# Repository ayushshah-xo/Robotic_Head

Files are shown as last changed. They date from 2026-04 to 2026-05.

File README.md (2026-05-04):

<div align="center">

Stack ticker

<br/>

# 🤖 Humanoid Robot

**An open-source AI-powered robot with real-time voice conversation, expressive servo-driven facial animations, and a fully 3D-printed chassis — built on Raspberry Pi 4.**

<br/>






</div>

---

## What is this?

A fully functional humanoid robot built from scratch — mechanical design, embedded hardware, and AI software — by a student. It listens to you, thinks, responds aloud, and moves its face to match.

No cloud subscriptions. No black-box kits. Every part designed, printed, and coded by hand.

<br/>

<div align="center">

| Robot front view | CAD design | System diagram |
|:---:|:---:|:---:|
| **Built Robot** | **CAD Design** | **System Flow** |

</div>

---

## Demo

https://github.com/user-attachments/assets/923eefe1-8b44-4f8e-96d7-886b42254e04

> Servo-driven facial expressions running in real time — eyes, eyebrows, and mouth animated independently.
>

---
## Features

| | |
|---|---|
| 🎤 **Voice I/O** | Listens via mic, responds via speaker |
| 🧠 **AI Brain** | Online + offline conversation modes |
| 😐 **Facial Expressions** | Servo-driven eyes, eyebrows, and mouth |
| ⚡ **Real-time** | Low-latency speech-to-response pipeline |
| 🧩 **Modular** | Swap hardware or swap AI model independently |
| 🖨️ **3D Printed** | Every structural part is printable and remixable |

---

## How it works

```
You speak
   ↓
Speech Recognition  ──── converts audio to text
   ↓
AI Model  ──────────────  generates a response
   ↓
Text-to-Speech  ─────────  synthesizes audio
   ↓
Speaker output  +  Servo animation  (synced mouth movement)
```

The servo controller runs in a separate thread so facial animation stays in sync with audio playback without blocking the main pipeline.

---

## Hardware

| Component | Purpose |
|---|---|
| Raspberry Pi 4 | Main compute |
| Servo motors (×3) | Face actuation |
| Servo driver board | PCA9685 |
| USB microphone | Speech input |
| Speaker + amplifier | Audio output |
| 5V regulated supply | Motor power |
| 3D printed chassis | Structure |

> Wiring guide and GPIO pin map are in [`docs/hardware-setup.md`](docs/hardware-setup.md)

---

## Getting started

**Requirements:** Python 3.9+, Raspberry Pi OS (64-bit recommended)

```bash
# 1. Clone
git clone https://github.com/ayushshah-xo/Humanoid-Robot-.git
cd Humanoid-Robot-

# 2. Install dependencies
pip install -r requirements.txt

# 3. Configure (copy and edit)
cp config.example.yaml config.yaml

# 4. Run
python3 main.py
```

> **First time?** See [`docs/quickstart.md`](docs/quickstart.md) for a step-by-step walkthrough including hardware connection and audio device setup.

---
## Libraries

Two kinds of dependencies power this project — Python packages and system-level tools.

**Python packages** — installed via pip:

| Package | Purpose |
|---|---|
| `adafruit-circuitpython-servokit` | PCA9685 servo driver control |
| `groq` | Online AI via Groq (Llama 3) |
| `SpeechRecognition` | Converts microphone audio to text |
| `pyaudio` | Raw audio stream for the mic |
| `requests` | HTTP calls to Groq and Ollama |
| `pyyaml` | Reads `config.yaml` at startup |

```bash
pip install -r requirements.txt
```

**System packages** — installed via apt:

| Package | Purpose |
|---|---|
| `espeak` | Offline text-to-speech engine |
| `python3-pyaudio` | PyAudio system binding |
| `portaudio19-dev` | Audio I/O backend |
| `alsa-utils` | Audio device control (`aplay`, `alsamixer`) |

```bash
sudo apt install espeak python3-pyaudio portaudio19-dev alsa-utils
```

**Offline AI engine** — Ollama runs locally on the Pi as a fallback when there is no internet:

```bash
curl -fsSL https://ollama.com/install.sh | sh
ollama pull tinyllama
```

> The robot automatically switches between Groq (online) and Ollama (offline) — no manual intervention needed.

---
## Folder structure
<p align="center">
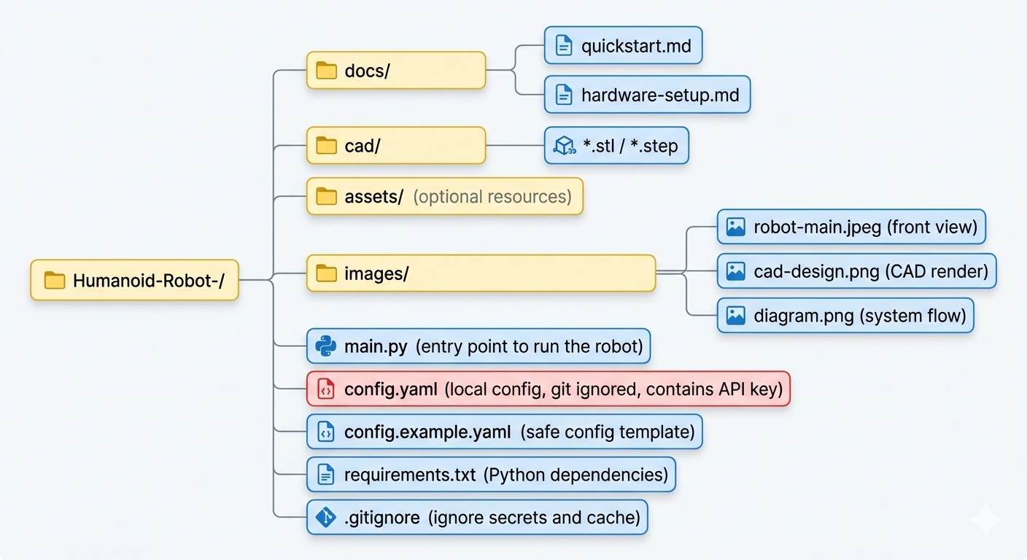
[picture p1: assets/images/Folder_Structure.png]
  
</p>

> ⚠️ config.yaml holds your API key — it is blocked by .gitignore and will never be pushed to GitHub. Only edit config.example.yaml when changing config structure.
---

## CAD & 3D printing

All structural files are in [`/cad`](cad/). Designed to be:

- Printed on any FDM printer (PLA recommended)
- Assembled with standard M3 hardware
- Modular — replace individual parts without reprinting everything

---

## Roadmap

- [ ] Face recognition — recognize known people
- [ ] Emotion AI — adapt expression to conversation tone
- [ ] Mobile app — wireless control and monitoring
- [ ] Locomotion — basic autonomous movement

---

## Contributing

Issues, pull requests, and forks are welcome.

If you improve a module or add a new one, open a PR — this project is meant to be remixed.

---

If this project helped you or inspired you — a ⭐ goes a long way.

</div>

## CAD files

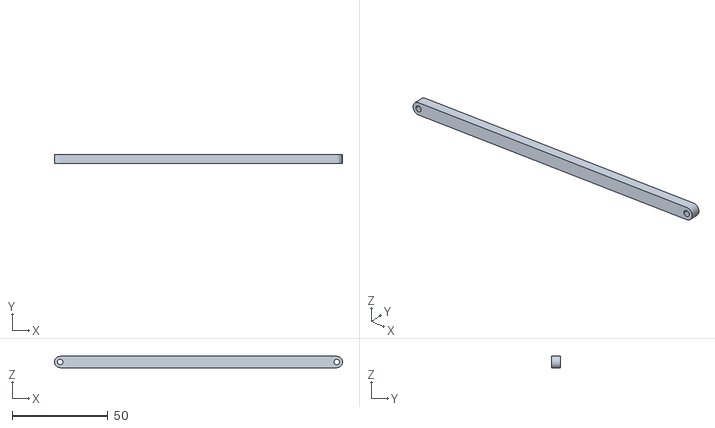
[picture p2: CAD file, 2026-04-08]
cad/Neck/neck_stroke.stl
150.2 x 4.70 x 6.00

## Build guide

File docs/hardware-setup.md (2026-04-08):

# 🤖 Hardware Setup — Humanoid Robot

> **This document explains every wire and connection in the robot.**
> Even if you've never built a robot before, you'll understand this by the end!

---

## 📋 Table of Contents

- [What's Inside the Robot?](#whats-inside-the-robot)
- [Parts List](#parts-list)
- [How Everything Connects](#how-everything-connects)
  - [Raspberry Pi → PCA9685 Servo Driver](#1-raspberry-pi--pca9685-servo-driver)
  - [Servo Motors (Eyes & Jaw)](#2-servo-motors-eyes--jaw)
  - [Power Supply](#3-power-supply)
  - [USB Microphone](#4-usb-microphone)
  - [Speaker (Audio Jack)](#5-speaker-audio-jack)
- [Wiring Diagram](#wiring-diagram)
- [Pinout Reference](#pinout-reference)
- [Quick-Reference Table](#quick-reference-table)
- [Credits](#credits)

---

## 🧠 What's Inside the Robot?

Think of the robot's brain like a tiny computer — that's the **Raspberry Pi 4**. It tells the eyes and jaw when to move, listens through a microphone, and talks through a speaker. The **PCA9685** is a helper chip that controls all the motors so the Raspberry Pi doesn't get overloaded.

```
[ Microphone ] ──USB──┐
[ Speaker ]  ──3.5mm──┤
                       ├──► Raspberry Pi 4 ──I2C──► PCA9685 ──PWM──► Servo Motors
[ 5V Power ] ─────────┘                                │
                                              [ 5V Power for Servos ]
```

---

## 🛒 Parts List

| # | Part | Quantity | What it does |
|---|---|---|---|
| 1 | Raspberry Pi 4 | 1 | The brain — runs all the code |
| 2 | PCA9685 16-Channel PWM Driver | 1 | Controls all servo motors |
| 3 | Servo Motor (for eye blinking) | 3 | Opens and closes the eyelids |
| 4 | Servo Motor (for jaw movement) | 1 | Opens and closes the mouth |
| 5 | USB Microphone | 1 | Listens to what you say |
| 6 | Speaker (3.5mm audio jack) | 1 | Lets the robot talk back |
| 7 | 5V Power Supply | 2 | Powers the Pi and the servos separately |
| 8 | Jumper Wires (Female-to-Female) | Several | Connect everything together |

---

## 🔌 How Everything Connects

### 1. Raspberry Pi → PCA9685 Servo Driver

The Raspberry Pi talks to the PCA9685 using a communication method called **I2C** — it only needs 4 wires!

> 💡 **Simple explanation:** I2C is like a telephone line. The Pi is the boss, and the PCA9685 picks up the call and moves the motors.

| Wire Color | Raspberry Pi Pin | PCA9685 Pin | Purpose |
|---|---|---|---|
| 🔴 Red | Pin 1 (3.3V) | VCC | Power for the chip's brain |
| ⚫ Black | Pin 6 (Ground) | GND | Completes the circuit (return path) |
| 🟡 Yellow | Pin 3 (BCM 2 / SDA) | SDA | Sends data |
| 🟢 Green | Pin 5 (BCM 3 / SCL) | SCL | Keeps data in sync (clock) |

---

### 2. Servo Motors (Eyes & Jaw)

Servo motors plug directly into the **PCA9685 board** using the PWM headers along the bottom edge. Each servo has 3 wires:

- 🔴 **Red** → V+ (Positive power)
- ⚫ **Brown/Black** → GND (Ground)
- 🟡 **Yellow/Orange** → PWM signal (tells the motor what angle to move to)

| Servo | PCA9685 Channel | Function |
|---|---|---|
| Eye Servo 1 | Channel 0 | Left eye blink |
| Eye Servo 2 | Channel 1 | Right eye blink |
| Eye Servo 3 | Channel 2 | Upper eyelid control |
| Jaw Servo | Channel 3 | Jaw open / close |

> 💡 **Simple explanation:** Imagine the PCA9685 is a TV remote. Each channel is a button, and each servo is a TV. Press button 0 → Eye 1 moves!

---

### 3. Power Supply

The robot needs **two separate power supplies**:

#### ⚡ Power for the Raspberry Pi
- Use an official **5V USB-C power adapter** (at least 3A recommended)
- Plug it directly into the **USB-C port** on the Raspberry Pi 4

#### ⚡ Power for the Servo Motors (via PCA9685)
- Use a **5V–6V DC power supply**
- Connect to the **V+** and **GND** screw terminals on the PCA9685 board
- Do **NOT** power servos from the Raspberry Pi's GPIO pins — they draw too much current and can damage the Pi

> ⚠️ **Important:** Always power servos from a separate supply. The Raspberry Pi is sensitive!

---

### 4. USB Microphone

This is the simplest connection in the whole build!

- Plug the USB microphone directly into any **USB-A port** on the Raspberry Pi 4
- The Raspberry Pi will automatically detect it — no setup needed

> 💡 **Simple explanation:** It works just like plugging a USB mouse into a laptop.

---

### 5. Speaker (Audio Jack)

- Plug the speaker's **3.5mm audio jack** into the **audio output port** on the Raspberry Pi 4
- This is the small round port on the side of the Pi (same size as a phone headphone jack)

> 💡 **Simple explanation:** It's exactly like plugging headphones into your phone.

---

## 🗺️ Wiring Diagram

The diagram below shows the full wiring between the Raspberry Pi and the PCA9685 servo driver. A separate 5V–6V supply connects to the servo power terminals.

Wiring Diagram — Raspberry Pi to PCA9685

*Full wiring overview: Raspberry Pi 4 → PCA9685 via I2C (4 wires). Servo power supplied separately via DC jack connector.*

---

## 📌 Pinout Reference

The image below shows exactly which pins on the Raspberry Pi are used and how they map to the PCA9685.

Raspberry Pi Pinout → PCA9685 Connection

| Pi GPIO Pin # | BCM Name | PCA9685 Label | Wire Color |
|---|---|---|---|
| Pin 1 | 3.3V Power | VCC | 🔴 Red |
| Pin 6 | Ground | GND | ⚫ Black |
| Pin 3 | BCM 2 (SDA) | SDA | 🟡 Yellow |
| Pin 5 | BCM 3 (SCL) | SCL | 🟢 Green |

---

## 📊 Quick-Reference Table

All connections at a glance:

| Component | Connection Point | Interface | Notes |
|---|---|---|---|
| PCA9685 Servo Driver | Raspberry Pi GPIO (Pins 1, 3, 5, 6) | I2C | Default I2C address: 0x40 |
| Eye Servo 1 | PCA9685 Channel 0 | PWM | Left eye blink |
| Eye Servo 2 | PCA9685 Channel 1 | PWM | Right eye blink |
| Eye Servo 3 | PCA9685 Channel 2 | PWM | Upper eyelid |
| Jaw Servo | PCA9685 Channel 3 | PWM | Jaw open/close |
| USB Microphone | Raspberry Pi USB-A Port | USB | Auto-detected |
| Speaker | Raspberry Pi 3.5mm Jack | Analog Audio | Plug-and-play |
| Pi Power Supply | Raspberry Pi USB-C | 5V / 3A+ | Official adapter recommended |
| Servo Power Supply | PCA9685 V+ / GND terminals | 5V–6V DC | Separate from Pi power |

---

## 👤 Credits

This hardware setup document is part of the **Humanoid Robot** open-source project.

**Created by:** Ayush Shah
**GitHub:** [@ayushshah-xo](https://github.com/ayushshah-xo)
**Project Repository:** [Humanoid-Robot-](https://github.com/ayushshah-xo/Humanoid-Robot-)

---

> 📁 *This file lives at `docs/hardware-setup.md` in the repository.*
> 💬 *Have questions or found an issue? Open an issue on GitHub — contributions are welcome!*

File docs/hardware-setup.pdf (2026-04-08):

# Hardware Setup Guide

Humanoid Robot — Raspberry Pi 4 + PCA9685

### Overview

This guide covers the electrical wiring between the Raspberry Pi 4 and the PCA9685 16-channel PWM servo driver, including servo motor power supply connections.

You will need:
- Raspberry Pi 4 (any RAM variant)
- Adafruit PCA9685 16-channel 12-bit PWM servo driver
- 5V–6V regulated power supply (for servos)
- Jumper wires (female-to-female)

### Section 1 — Raspberry Pi to PCA9685 (I²C)

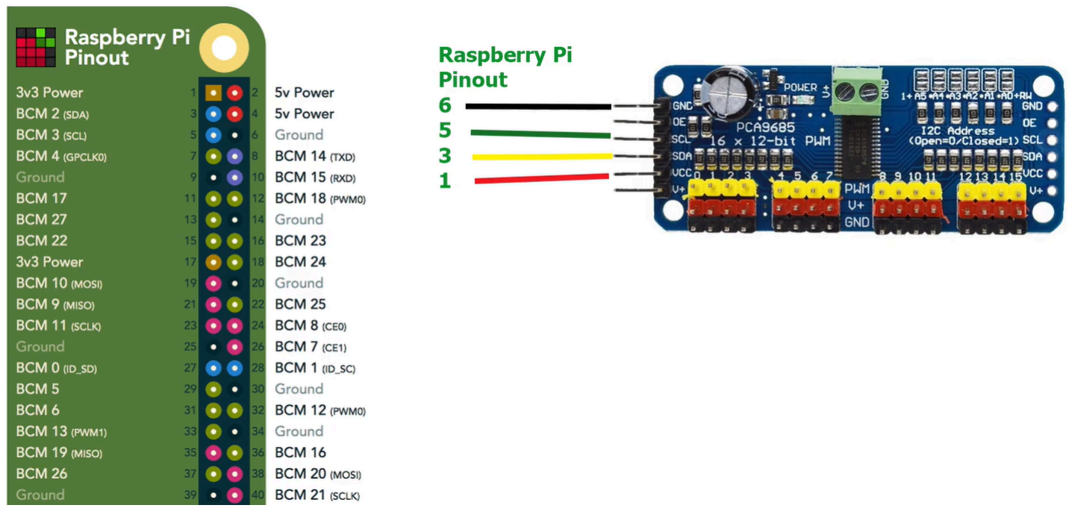
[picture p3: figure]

The PCA9685 communicates over I²C. Connect four wires from the Raspberry Pi GPIO header to the PCA9685 input pins as shown below.

Wire Color | Pi Physical Pin | Pi Function | PCA9685 Pin
Red | Pin 1 | 3.3V Power | VCC

Black | Pin 6 | Ground | GND
Yellow | Pin 3 | BCM 2 (SDA) | SDA
Green | Pin 5 | BCM 3 (SCL) | SCL

Note: Use 3.3V (Pin 1) for VCC — not 5V. The PCA9685 logic runs at 3.3V. The V+ terminal on the board is for servo power only (see Section 2).

I²C Pin Reference (Pi GPIO Header)

Function | BCM Number | Physical Pin
SDA (Data) | BCM 2 | Pin 3
SCL (Clock) | BCM 3 | Pin 5
Ground | — | Pin 6 (or any GND pin)
3.3V Power | — | Pin 1 (or Pin 17)

### Section 2 — Servo Motor Power Supply

Servo motors draw significant current and must be powered separately — do not power them from the Pi's 5V pins. Use a dedicated 5V–6V regulated supply connected to the PCA9685 V+ terminal block.

Wire | From | To | Notes
Power (+) | PSU positive terminal | PCA9685 V+ | 5V–6V regulated
Ground (−) | PSU negative terminal | PCA9685 GND | Must share ground with Pi

Note: Always connect the power supply ground (GND) to the same ground rail as the Raspberry Pi. Without a common ground, signals will not reference correctly and servos will behave erratically.

### Section 3 — Enable I²C on Raspberry Pi

I²C is disabled by default. Enable it before running any code.

Option A — raspi-config (recommended):
sudo raspi-config
Navigate to: Interface Options → I2C → Yes → Finish → Reboot

Option B — manual config.txt edit:
echo 'dtparam=i2c_arm=on' | sudo tee -a /boot/config.txt && sudo reboot

Verify the connection:
sudo i2cdetect -y 1
You should see address 0x40 (or 0x41–0x7F if address pins A0–A5 are bridged). If no address appears, recheck wiring.

### Quick Checklist

# | Check | Status

1 | SDA → Pin 3 (BCM 2) | ☐
2 | SCL → Pin 5 (BCM 3) | ☐
3 | VCC → Pin 1 (3.3V) | ☐
4 | GND → Pin 6 | ☐
5 | Servo V+ connected to 5V–6V PSU | ☐
6 | PSU GND shares ground with Pi | ☐
7 | I²C enabled via raspi-config | ☐
8 | i2cdetect shows address 0x40 | ☐

Humanoid Robot Project · github.com/ayushshah-xo/Humanoid-Robot-

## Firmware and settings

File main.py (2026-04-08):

import time
import math
import random
import requests
import threading
import subprocess
import socket
import yaml
import speech_recognition as sr
from adafruit_servokit import ServoKit
from groq import Groq

# ─── Load Config ──────────────────────────────────────────────
with open("config.yaml", "r") as f:
    config = yaml.safe_load(f)

GROQ_API_KEY  = config["groq"]["api_key"]
OUTPUT_CARD   = config["audio"]["output_card"]
INPUT_DEVICE  = config["audio"]["input_device"]
ESPEAK_SPEED  = str(config["audio"]["espeak_speed"])
ESPEAK_PITCH  = str(config["audio"]["espeak_pitch"])
JAW_CLOSED    = config["servo"]["jaw_closed"]
JAW_OPEN      = config["servo"]["jaw_open"]
BROW_DOWN     = config["servo"]["brow_down"]
BROW_UP       = config["servo"]["brow_up"]
GROQ_MODEL    = config["ai"]["groq_model"]
OLLAMA_MODEL  = config["ai"]["ollama_model"]
MAX_TOKENS    = config["ai"]["max_tokens"]
PERSONALITY   = config["ai"]["personality"]
AUDIO_DEVICE  = f"hw:{OUTPUT_CARD},0"

# ─── Hardware Setup ───────────────────────────────────────────
kit = ServoKit(channels=16)
for ch in [0, 4, 5]:
    kit.servo[ch].set_pulse_width_range(500, 2500)

# ─── Servo Movement ───────────────────────────────────────────
def move_jaw(open=True, duration=0.12, steps=40):
    jaw_start = JAW_CLOSED if open else JAW_OPEN
    jaw_end   = JAW_OPEN   if open else JAW_CLOSED
    for i in range(steps + 1):
        t = i / steps
        e = -(math.cos(math.pi * t) - 1) / 2
        kit.servo[0].angle = jaw_start + e * (jaw_end - jaw_start)
        time.sleep(duration / steps)

def move_brows(up=True, duration=0.15, steps=40):
    left_start  = BROW_DOWN if up else BROW_UP
    left_end    = BROW_UP   if up else BROW_DOWN
    right_start = BROW_UP   if up else BROW_DOWN
    right_end   = BROW_DOWN if up else BROW_UP
    for i in range(steps + 1):
        t = i / steps
        e = -(math.cos(math.pi * t) - 1) / 2
        kit.servo[4].angle = left_start  + e * (left_end  - left_start)
        kit.servo[5].angle = right_start + e * (right_end - right_start)
        time.sleep(duration / steps)

def neutral():
    kit.servo[0].angle = JAW_CLOSED
    kit.servo[4].angle = BROW_DOWN
    kit.servo[5].angle = BROW_UP

# ─── Blink Loop ───────────────────────────────────────────────
brow_lock = threading.Lock()

def blink_loop():
    while True:
        time.sleep(random.uniform(2.5, 3.5))
        with brow_lock:
            move_brows(up=True,  duration=0.15)
            time.sleep(0.1)
            move_brows(up=False, duration=0.15)

blink_thread = threading.Thread(target=blink_loop)
blink_thread.daemon = True
blink_thread.start()

# ─── Speak ────────────────────────────────────────────────────
def speak(text):
    print(f"Sukuna: {text}")
    stop_flag = [False]

    def jaw_loop():
        while not stop_flag[0]:
            move_jaw(open=True,  duration=0.12)
            time.sleep(0.05)
            move_jaw(open=False, duration=0.12)
            time.sleep(0.1)

    t = threading.Thread(target=jaw_loop)
    t.daemon = True
    t.start()

    subprocess.run(["espeak", "-v", "en", "-s", ESPEAK_SPEED, "-p", ESPEAK_PITCH, "-w", "/tmp/sukuna.wav", text])
    subprocess.run(["aplay", "-D", AUDIO_DEVICE, "/tmp/sukuna.wav"])

    stop_flag[0] = True
    t.join()
    neutral()

# ─── Internet Check ───────────────────────────────────────────
def is_connected():
    try:
        r = requests.get("https://www.google.com", timeout=5)
        if r.status_code == 200:
            print("Internet: Connected")
            return True
    except:
        pass
    print("Internet: Not connected")
    return False

# ─── Groq (Online) ────────────────────────────────────────────
def ask_groq(question):
    try:
        print("Internet found, asking Groq...")
        client = Groq(api_key=GROQ_API_KEY)
        chat = client.chat.completions.create(
            model=GROQ_MODEL,
            max_tokens=MAX_TOKENS,
            messages=[
                {"role": "system", "content": PERSONALITY},
                {"role": "user",   "content": question}
            ]
        )
        return chat.choices[0].message.content
    except Exception as e:
        print(f"Groq error: {e}")
        return None

# ─── Ollama (Offline) ─────────────────────────────────────────
def ask_ollama(question):
    try:
        print("No internet, asking Ollama...")
        r = requests.post("http://localhost:11434/api/generate",
            json={"model": OLLAMA_MODEL,
                  "prompt": f"Answer in 2 sentences: {question}",
                  "num_predict": 60,
                  "stream": False},
            timeout=60)
        return r.json()["response"]
    except Exception as e:
        print(f"Ollama error: {e}")
        return "I cannot answer right now."

# ─── Smart Ask ────────────────────────────────────────────────
def ask(question):
    if is_connected():
        answer = ask_groq(question)
        if answer:
            return answer
        print("Groq failed, falling back to Ollama...")
        return ask_ollama(question)
    else:
        print("No internet, using Ollama...")
        return ask_ollama(question)

# ─── Listen ───────────────────────────────────────────────────
def listen():
    r = sr.Recognizer()
    r.energy_threshold = 150
    r.dynamic_energy_threshold = False
    r.pause_threshold = 0.8
    mic = sr.Microphone(device_index=INPUT_DEVICE)
    print("Listening... (speak now)")
    with mic as source:
        try:
            audio = r.listen(source, timeout=8, phrase_time_limit=8)
            text = r.recognize_google(audio).lower()
            print(f"Heard: {text}")
            return text
        except sr.UnknownValueError:
            print("Could not understand")
            return ""
        except sr.WaitTimeoutError:
            print("Timeout")
            return ""
        except Exception as e:
            print(f"Error: {e}")
            return ""

# ─── Main Loop ────────────────────────────────────────────────
print("Sukuna starting...")
neutral()
speak("Sukuna is ready.")

while True:
    input("Press ENTER then say your question...")
    time.sleep(0.5)
    question = listen()
    if question:
        speak("Let me think.")
        answer = ask(question)
        speak(answer)
    neutral()

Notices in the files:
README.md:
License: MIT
